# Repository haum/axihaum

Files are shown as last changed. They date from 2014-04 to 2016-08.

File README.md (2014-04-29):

axihaum
=======

Ce dépôt contient les fichiers concernant la fraiseuse numérique du HAUM, basée sur une LPKS ProtoMat 91s.

Des photos de la LPKS ProtoMat 91S telle que nous l'avons reçu sont disponibles ici:
https://secure.flickr.com/photos/111893015@N07/sets/72157638807824124/

Quelques régles de nommage:
Les fichiers DXF ainsi que les couches (DXF et FreeCAD) sont nommé de la façon suivante:

Y_P_L.dxf

 - où Y est l'initiale la partie concernée (X, Y, Z et C pour le chassis)
 - où P est l'initiale de la sous-partie concernée (Part, Guide, Screw)
 - où L est l'initiale du coté concerné (Left, Right, Up, Down)

Les axes X, Y et Z sont nommé du plus grand (X) au plus petit (Z).
Note: dans la version originale, Z n'est pas motorisé.

Pour le nommage et les vues, on considère la fraiseuse vue de face dans le prolongement de l'axe X (axe le plus long), l'axe Y étendu de gauche à droite, Z de haut en bas.

Fichiers:

 * DXF (2D)
   - X_SY_RT: X, Support for Y, Right Top (also used as Left in 3D)
   - X_SY_LM: X, Support for Y, Left Middle
   - X_SY_RM: X, Support for Y, Right Middle
   - X_SY_B: X, Support for Y, Bottom
   - Y_P_L: Y, Part, Left
   - Y_P_R: Y, Part, Right
   - C_T: Case, Table

 * FreeCAD (3D)
   - LPKS_ProtoMat: modèlisation de la LPKS ProtoMat 91s (original)
   - axihaum: modèlisation de la version modifiée de la LPKS
   - C_T: Chassic, Table
   - A_LB: Accessories, Linear Bearing
   - A_M: Accessories, NEMA23 Motor
   - A_T: Accessories, Transmission
   - A_FME-1_1050: Accessories, Spindle model based on Kress FME-1 1050
   - A_C_NEMA23: Accessories, NEMA23 coupler (D6.35 -> D8)
   - A_T: Accessories, Transmission (with Top, Left/Right, Bottom as separate files)
   - A_LB_SBR12UU: Accessories, Linear Bearing, SBR12UU
   - Z_P: Z, Panel
   - Z_S: Z, Support

Notes:
 * les premières parties de la modèlisation 3D ont été réalisées à partir d'imports de DXF, extrudés et soustraits.
 * les pièces suivantes (à partir de C_T) utilisent les esquisses 2D intégré dans FreeCAD. Les fichiers DXF correspondant peuvent être crées au besoin.

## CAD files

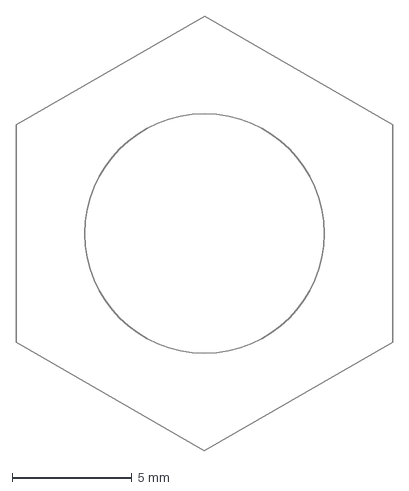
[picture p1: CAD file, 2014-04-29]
A_M10.dxf
15.7 x 18.1 mm

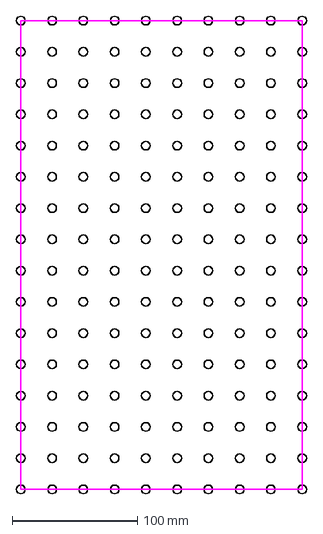
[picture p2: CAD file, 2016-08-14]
martyr/martyr.dxf
232.0 x 382.0 mm

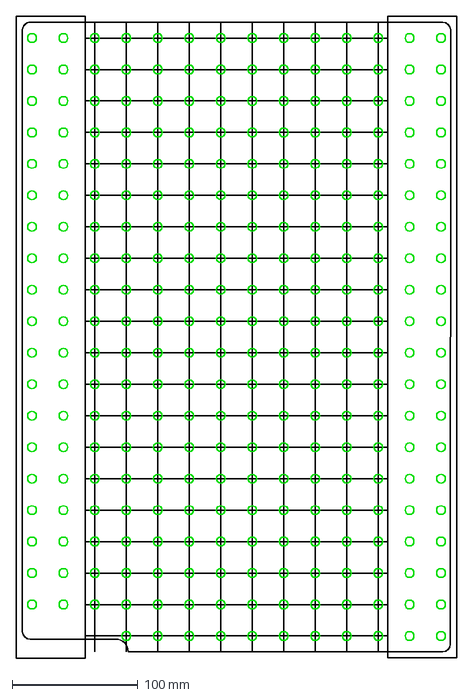
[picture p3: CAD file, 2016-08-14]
table/table_fixation.dxf
350.0 x 510.0 mm

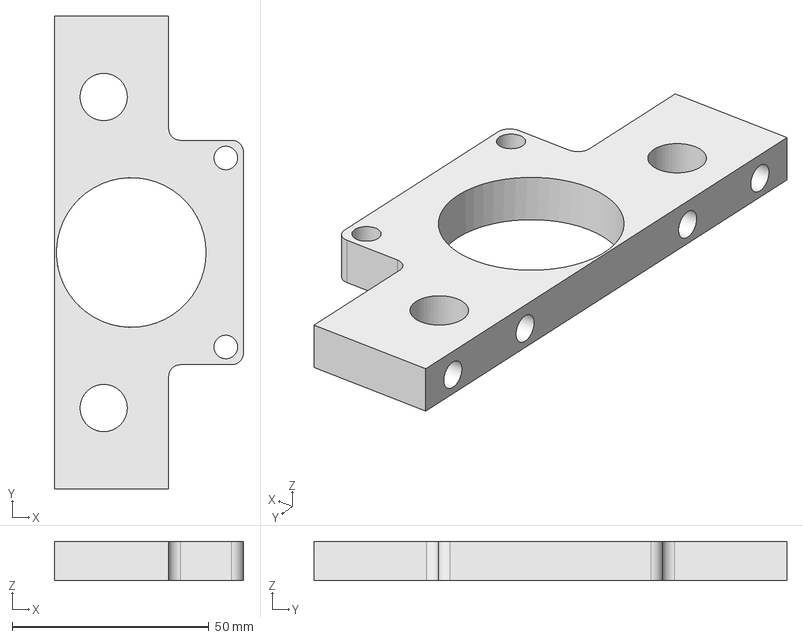
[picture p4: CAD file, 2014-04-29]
Z_T.FCStd
48.0 x 120.0 x 10.0 mm

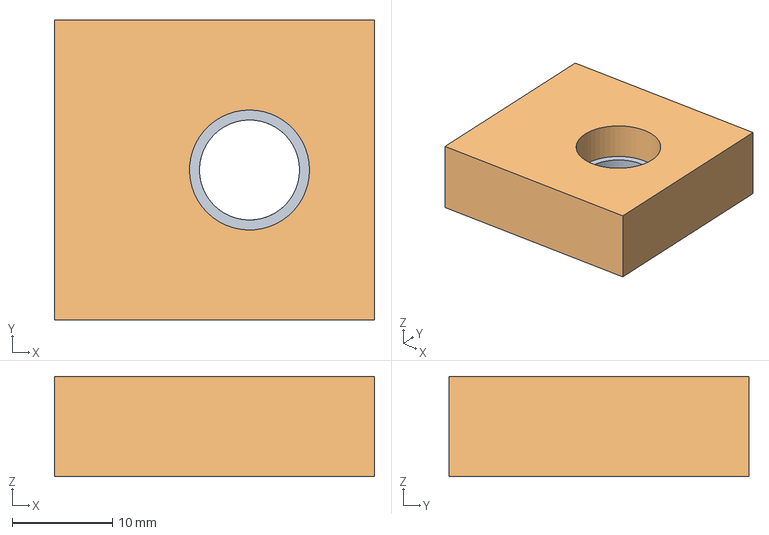
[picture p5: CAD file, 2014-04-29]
Z_T_SB_T.FCStd
32.0 x 30.0 x 10.0 mm

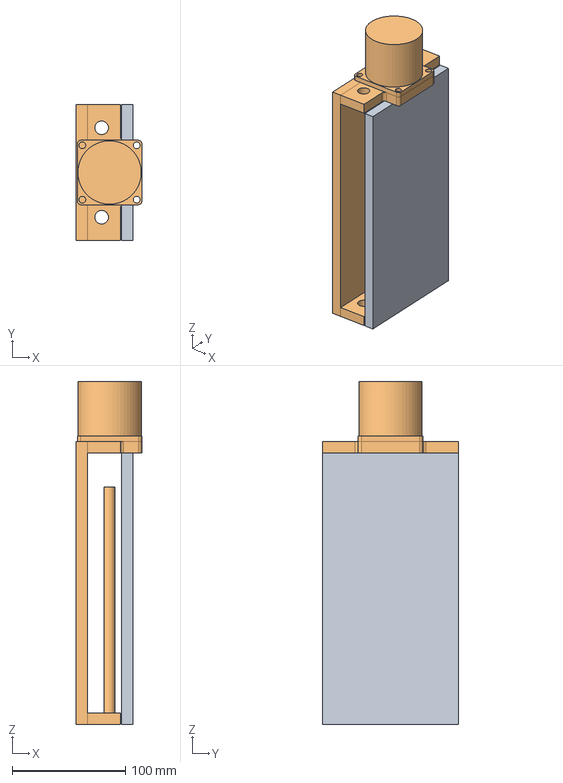
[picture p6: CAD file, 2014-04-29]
Z.FCStd
58.0 x 120.0 x 303.0 mm

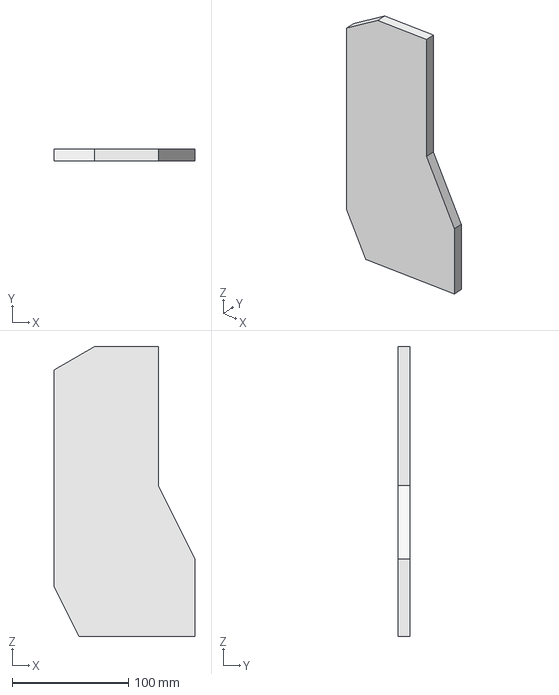
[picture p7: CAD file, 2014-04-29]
Y_SZ_R.FCStd
121.4 x 10.0 x 250.0 mm

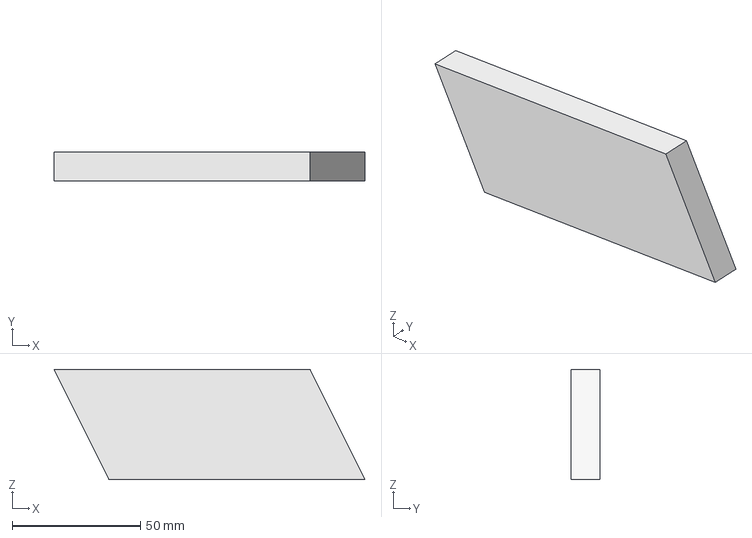
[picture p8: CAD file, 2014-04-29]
X_SY_M.FCStd
121.4 x 11.5 x 43.0 mm

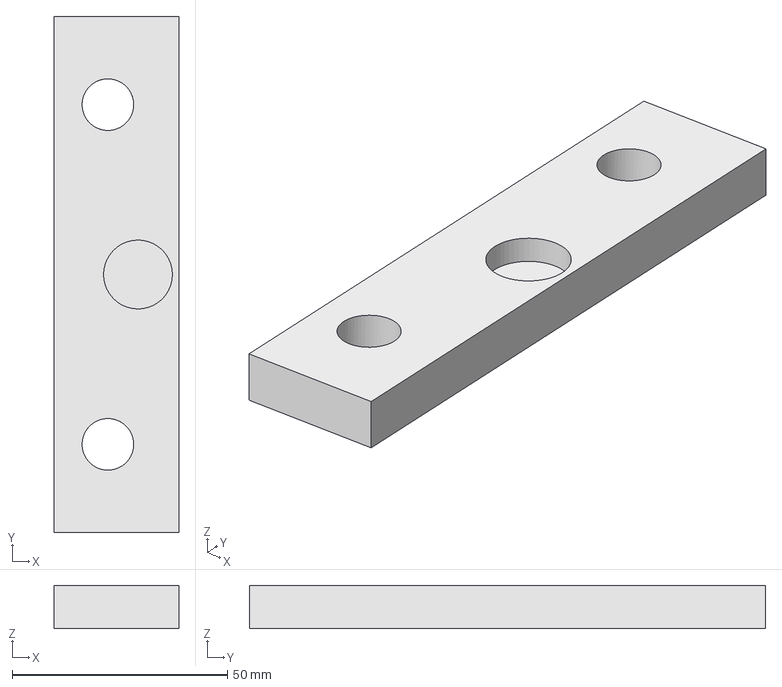
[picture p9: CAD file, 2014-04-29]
Z_B.FCStd
29.0 x 120.0 x 10.0 mm

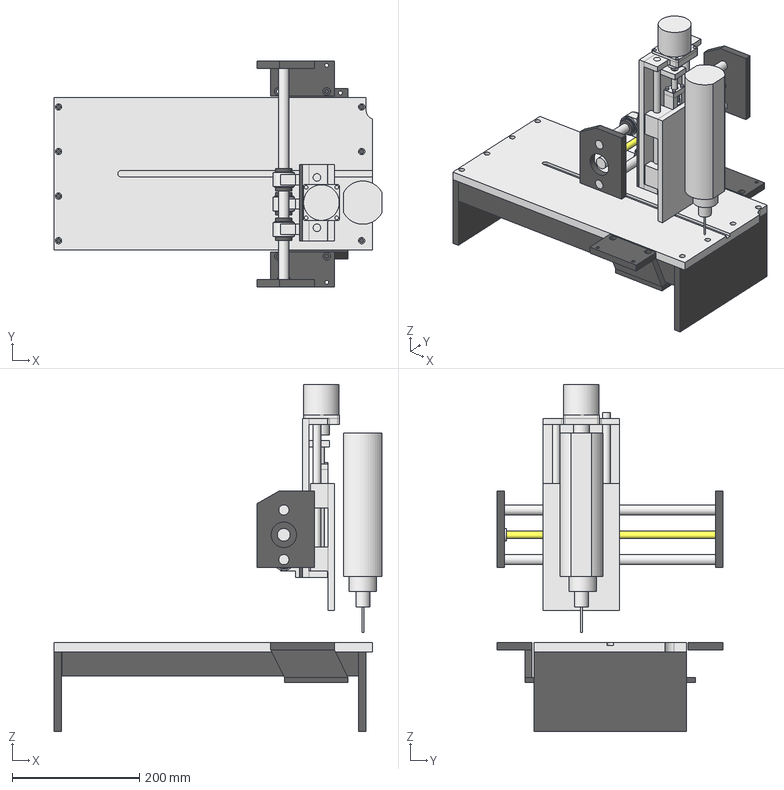
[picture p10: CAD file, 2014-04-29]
axihaum.fcstd
514.8 x 355.2 x 544.9 mm
Y_P_L
Y_G_U
Y_G_D
Y_P_R
Y_SC
Y_S
A_LB_Y0_alu
A_LB_Y0_plastic
A_LB_Y1_plastic
A_LB_Y1_alu
A_LB_Y2_plastic
A_LB_Y2_alu
X_SY_RT
X_SY_LT
X_SY_B
X_SY_M
C_T
C_B
C_F
X Axis
Z_P
Z_B
Z_G_L
Z_G_R
Z_F_spindle
Z_C
Z_T_SB_T
Z_T

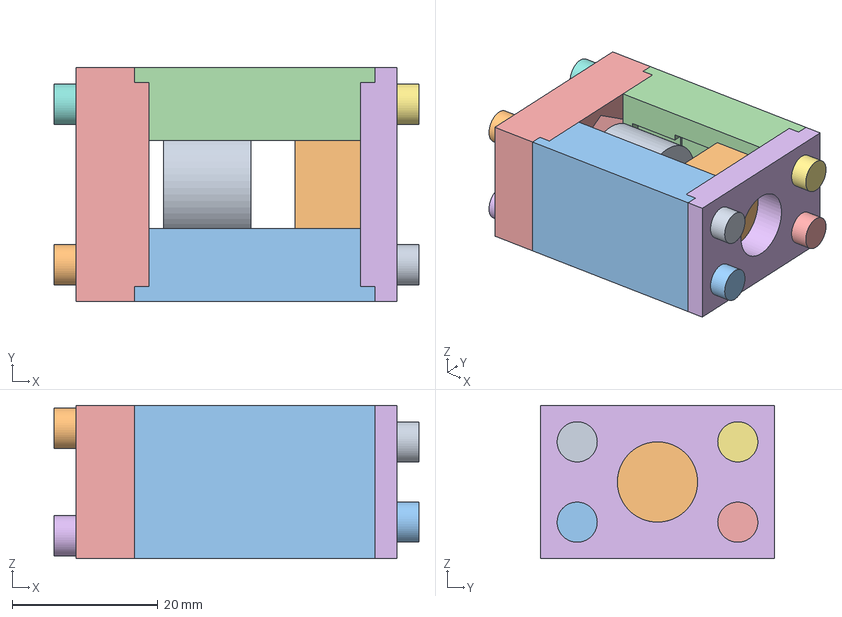
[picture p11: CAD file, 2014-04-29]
A_T.fcstd
50.0 x 32.0 x 21.0 mm
DIN912_M3_001
DIN912_M3_002
DIN912_M3_003
DIN912_M3_004
DIN912_M3_005
DIN912_M3_006
DIN912_M3_007
DIN912_M3_008

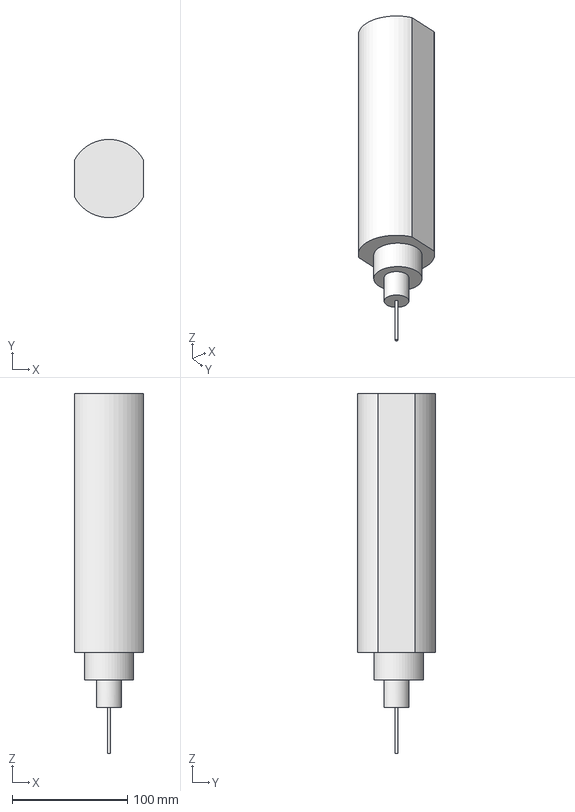
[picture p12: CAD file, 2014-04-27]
A_FME-1_1050.fcstd
60.0 x 68.0 x 313.0 mm

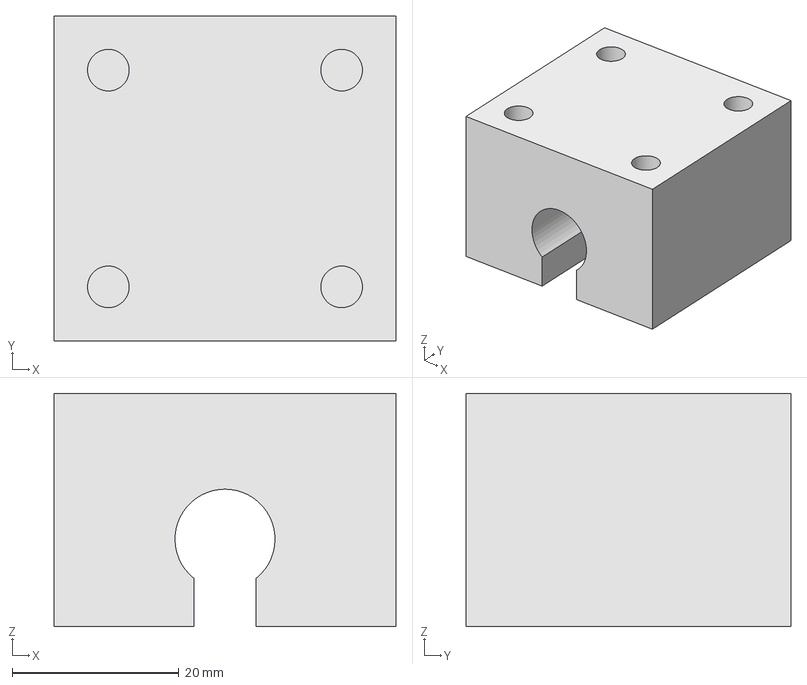
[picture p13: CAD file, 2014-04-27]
A_SBR12UU.fcstd
41.0 x 39.0 x 28.0 mm

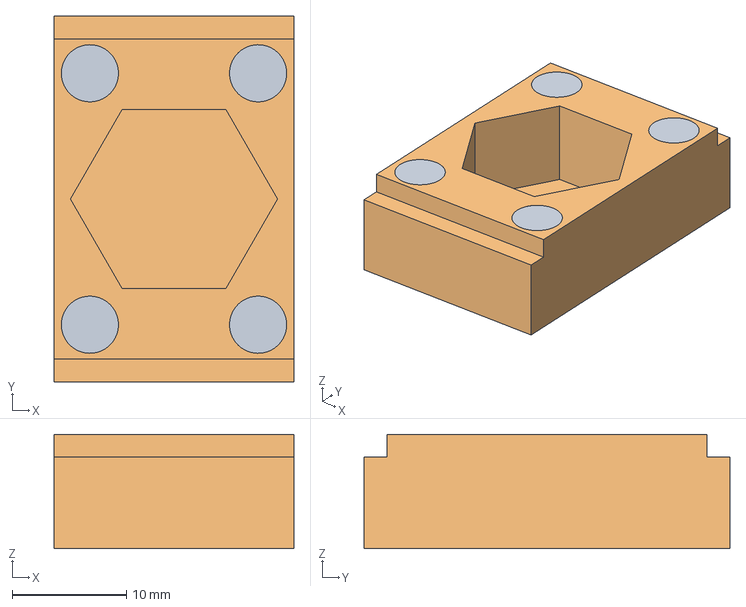
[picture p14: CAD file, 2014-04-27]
A_T_B.fcstd
21.0 x 32.0 x 10.0 mm

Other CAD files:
A_T_T.fcstd
A_T_LR.fcstd
A_C_NEMA23.FCStd
A_M.fcstd
A_LB.fcstd
C_T.FCStd
C_T.dxf
LPKS_ProtoMat_91s.fcstd
X_SY_B.dxf
X_SY_LM.dxf
X_SY_RM.dxf
X_SY_RT.dxf
Y_P_L.dxf
Y_P_R.dxf
Z_P.fcstd
Z_S.fcstd
axihaum-modif.fcstd

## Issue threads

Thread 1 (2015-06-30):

Résoudre le problème de l'entrainement du Z qui "danse"

MicroJoe, 2015-06-30:
Détails : https://github.com/haum/haum_internal/issues/9

jblb, 2015-07-10:
la cause est identifiée elle vient de mon tour et de la façon dont a été usinée la pièce. Comme ce problème de concentricité se reproduira lors de d'autres usinage j'ai fait l’acquisition de pinces de précision pour pouvoir faire ce genre d'usinage. Il suffira de racheter une tige filetée inox et de refaire les usinages.

Matael, 2015-07-12:
Pour réusiner une plaque il faudra aussi s'équiper d'une broche avec assez de patate...

Matael, 2015-07-12:
Il faudra aussi s'équiper d'une broche capable de réusiner une plaque aussi...

neomilium, 2015-07-12:
@matael tu parles probablement de l'issue https://github.com/haum/axihaum/issues/5

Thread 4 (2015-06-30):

Équiper la machine d'une broche d'usinage de hobbyistes

MicroJoe, 2015-06-30:
Détails : https://github.com/haum/haum_internal/issues/12

jblb, 2015-07-12:
pourquoi pas quelque chose comme ça
- sans contrôleur $84.99
http://www.ebay.com/itm/400W-DC-12-48-CNC-Spindle-Motor-Mount-Bracket-24V-36V-For-Engraving-Carving-New-/171637806596
- avec contrôleur pilotable par le PC $99.99
http://www.ebay.com/itm/400W-CNC-Air-cooled-Spindle-Motor-Kit-PWM-Speed-Controller-With-Mount-Bracket-/321343321323
- avec contrôleur, alim et le jeu de pince $165.00
http://www.ebay.com/itm/CNC-400W-Spindle-Motor-Mach3-PWM-controller-Mount-Power-supply-ER11-collet/281732632226

on quadruple la puissance par rapport à ce que l'on as actuellement et les pinces en ER11 permettent de prendre aussi des fraises en queue de 6 ou tout autre diamètre si on s'équipe avec les bonnes pinces.

neomilium, 2015-07-15:
Il faut s'accorder sur le dureté maximale qu'on souhaite usiner... car même si le kit à l'air sympa, j'ai un doute sur sa capacité à usiner de l'aluminium (ou autre métal mou, tel que cuivre et laiton)

neomilium, 2015-07-15:
Un autre point à ne surtout pas négliger est la capacité de la broche choisie à pouvoir avoir une vitesse de rotation basse en gardant un bon couple.
Typiquement, lors que j'usine avec nos fraiseuses, on est toujours en dessous de 10000 trs/min et très souvent vers 5000...
PS: le kit proposé par @jblb semble correspondre à ce critère

neomilium, 2015-07-15:
À titre de comparaison (prix, puissance, qualité) :
 * http://damencnc.com/en/tools/kress/kress-milling-motor/87
 * http://www.ironwood-distribution.com/pinces_de_serrage/pinces_kress-c-281_282.html

Ce type de broche est potentiellement surdimensionner pour AxiHaum mais permet de faire de l'alu..

MicroJoe, 2015-07-15:
Avec l'équipement proposé par @neomilium ça nous fait 152 € contre les 165 $ de ce qu'a proposé @jblb, c'est donc moins cher si la broche possède tout ce qui est alimentation + contrôleur.

jblb, 2015-07-15:
Question puissance j'usine de l'alu avec la dremel actuelle ....
La broche proposée par @neomilium est une valeur sure, une référence en la matière qui nous fera usage un certain temps et qui est même facilement réparable quand les roulements de tête sont usés. Certe elle un peu surdimensionnée mais qui peu le plus peu le moins. Dans mon idée elle coutait beaucoup plus cher que ça et les pinces supplémentaires étaient hors de prix, je constate que ce n'est plus le cas, au moins chez http://damencnc.com/
La seule chose que l'on as pas avec cette solution c'est le réglage de la vitesse de rotation depuis le PC mais est ce bien utile dans notre cas ?

si je le compte:
une machine 138€99
une paire de charbons 9€99
un bloc de montage 28€99
une pince de 6.00 mm  19€99

Port et emballage  15€98

soit un total HT de  213€94

TVA (21%):  	44€93

Total: TTC  	258€87

le Haum a il cette somme à mettre dans la broche de la machine ?

Ps: je fait un mail sur la liste pour que tout le monde soit au courant de cette discussion.

Matael, 2015-07-15:
C'est un investissement dont on discute depuis longtemps et qui risque d'être utile pendant longtemps aussi. A moins que @fredblain ou Armelle soit fondamentalement contre, je pense qu'il faut y aller.

Avoir une bonne broche, c'est aussi pouvoir réusiner la plaque du Z pour complèter la machine et ouvrir la voie à des projets nécessitant plus d'usinage. Ce sera aussi l'occasion d'un talk/miniconf/whatever pour présenter l'anatomie d'une fraiseuse et ses capacités.

fredblain, 2015-07-15:
Vous pouvez y aller je n'ai rien contre, bien au contraire. Et si un apport est necessaire pour financer cet investisement, je suis pret a participer.

ACudennec, 2015-07-15:
Je suis pour et avait déjà envisagé cet achat.

neomilium, 2015-07-15:
Ne vous pressez pas pour commander : si ça peut attendre mardi, on en
discutera de vive voix...

Le 15 juillet 2015 14:56, ACudennec <notifications@github.com> a écrit :

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

--
Romuald

ACudennec, 2015-07-16:
Nous en discutons évidemment ensemble mardi prochain.

jblb, 2015-07-16:
Quoting Romuald Conty <notifications@github.com>:

> Ne vous pressez pas pour commander : si ça peut attendre mardi, on en
> discutera de vive voix...

Bon c'est bien parce que c'est toi qui le propose, mais je dit que
c'est la derniere limite :)

--
@+
jérôme

rebrec, 2015-07-16:
Je pense également que c'est une bonne idée, et s'il faut rajouter un peu
d'argent, je veux bien participer
Le jeu. 16 juil. 2015 à 10:19, JbLb <notifications@github.com> a écrit :

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

neomilium, 2015-07-16:
@rebrec : tu as payé ta cotisation ? Si non, commence par là :)

Le 16 juillet 2015 11:55, rebrec <notifications@github.com> a écrit :

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

--
Romuald

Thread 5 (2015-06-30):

Refaire la plaque Z

MicroJoe, 2015-06-30:
Détails : https://github.com/haum/haum_internal/issues/13

jblb, 2015-07-12:
il faut d’abord régler #1 #4 et #6

neomilium, 2015-07-13:
Je peux refaire cette plaque sur une de nos machines aussi...

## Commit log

2014-03-20 Add first part Y_P_L (2D/3D), Y axis guides (3D) and some useful README instructions
    [Y_P_L.dxf, axihaum.FCStd]
2014-03-20 3D: put Y axis in natural view for original CNC version
    [axihaum.FCStd]
2014-03-20 Add Y_P_R (2D/3D) and Y screw with shaft coupler (3D)
    [Y_P_R.dxf, axihaum.FCStd]
2014-03-20 Y_P_R: Add motor drills
    [Y_P_R.dxf]
2014-03-20 Add Y support parts on X (2D/3D)
    [X_SY_RT.dxf, axihaum.FCStd]
2014-03-21 Add support (middle part) for Y on X (2D/3D)
    [X_SY_LM.dxf, axihaum.FCStd]
2014-03-21 Add support (middle part, right) for Y on X (2D/3D)
    [X_SY_RM.dxf, axihaum.FCStd]
2014-03-21 Add bottom of Y support on X
    [X_SY_B.dxf, axihaum.FCStd]
2014-03-23 Add chassis table
    [C_T.FCStd, C_T.dxf]
2014-03-23 Import C_T in general axihaum modeling
    Please note that import is a "Duplicate" result of final element of C_T.
    It causes some troubles to FreeCAD when you try to edit (ie.double-click) this object within axihaum general file.
    This problem (NULL pointer exception) seems due to missing scketchs "Duplicate" function should theorically avoid this problem.
    This bug have been seen using FreeCAD 0.13 1830 tagged as stable at writing time.
    [axihaum.FCStd]
2014-03-24 Add front and back panels.
    Please note that these panels are partially draw: guides, axis/motor and regular drills are missing
    [axihaum.FCStd]
2014-03-24 Add dummmy X axis box.
    This part should be replaced by multiples parts, which are not required for our hack right now.
    [axihaum.FCStd]
2014-03-24 Improve standard view
    Move and rotate all elements to have front of table on front of axiometric view.
    Move origin to top left corner of table, this way coordinates in FreeCAD will fit with axihaum coordinates
    [axihaum.FCStd]
2014-03-24 Add Linear Bear model
    [A_LB.fcstd]
2014-03-24 Add Z panel model
    [Z_P.fcstd]
2014-03-24 Add Z support (panel + 3 linear bearings)
    [Z_S.fcstd]
2014-03-24 Put new pieces in general assembly file
    [axihaum.FCStd]
2014-03-24 Order elements with some groups
    [axihaum.FCStd]
2014-03-24 Draft a solution for Z axis
    [axihaum-modif.fcstd]
2014-03-28 Add NEMA23 motor model
    [A_M.fcstd]
2014-04-27 Add NEMA23 coupler (D6.35 -> D8)
    [A_C_NEMA23.FCStd]
2014-04-27 Add some transmission parts (see README)
    [A_T.fcstd, A_T_B.fcstd, A_T_LR.fcstd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]
2014-04-27 Add linear bearing SBR12UU
    [A_SBR12UU.fcstd]
2014-04-27 Add a draft of Kress FME-1 1050
    [A_FME-1_1050.fcstd]
2014-04-29 Finalize transmission
    [A_T.fcstd]
2014-04-29 Rename axihaum file as its an original modeling of LPKS ProtoMat 91s
    Note: its a partial representation: X axis modeling is missing
    [LPKS_ProtoMat_91s.fcstd]
2014-04-29 Add Axihaum model
    Its a draft used to test virtually Z axis add on LPKS ProtoMat 91s
    [axihaum.fcstd]
2014-04-29 Add Z axis bottom panel
    This panel grab the two guides and have a pocket for transmission end bearing
    [Z_B.FCStd]
2014-04-29 Draw 3D model for middle part of Y support (X axis)
    [X_SY_M.FCStd]
2014-04-29 Add right side of Z support (Y axis)
    Note: this is partial, screw-related drills and pockets are missing
    [Y_SZ_R.FCStd]
2014-04-29 Add partial Z axis model used in Axihaum model
    [Z.FCStd]
2014-04-29 Add bearing support for Z transmission
    This part will be place between coupler and first bearing to lock transmission screw
    [Z_T_SB_T.FCStd]
2014-04-29 Add Z axis top panel
    [Z_T.FCStd]
2014-04-29 2D: add M10 nut
    [A_M10.dxf]
2016-08-13 Add martyr plans
    [martyr.dxf, martyr_usinage.dxf]
2016-08-14 Add table plans
    [table_fixation.dxf]
2016-08-14 Fix martyr plans
    [martyr.dxf, martyr_usinage.dxf]
